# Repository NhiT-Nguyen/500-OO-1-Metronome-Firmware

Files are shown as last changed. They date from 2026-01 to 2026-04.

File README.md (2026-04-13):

# Metronome Glasses Firmware

The firmware of Metrnome Glasses was developed with Arduino and the Espressif ESP32 Library.
Other libraries were used to implement video on the glasses, and an I2S Protocol was used for the associated audio.

# Mechanical Enclosure

Included in this repository are the .stl files needed to 3D print the mechanical frame of the glasses.
The design of these parts were largely adapted from the Mentra Open Source Smart Glasses,
with adaptations made by the Tempo Titans team to suit our use case.

# Altium Design Files - PCB
This repository contains the PCB design files for the Tempo Titans custom board, designed in Altium Designer and fabricated by JLCPCB.

# Sister Repository

This repository is the sister repository of the Flutter app used to configure the glasses' metronome settings.

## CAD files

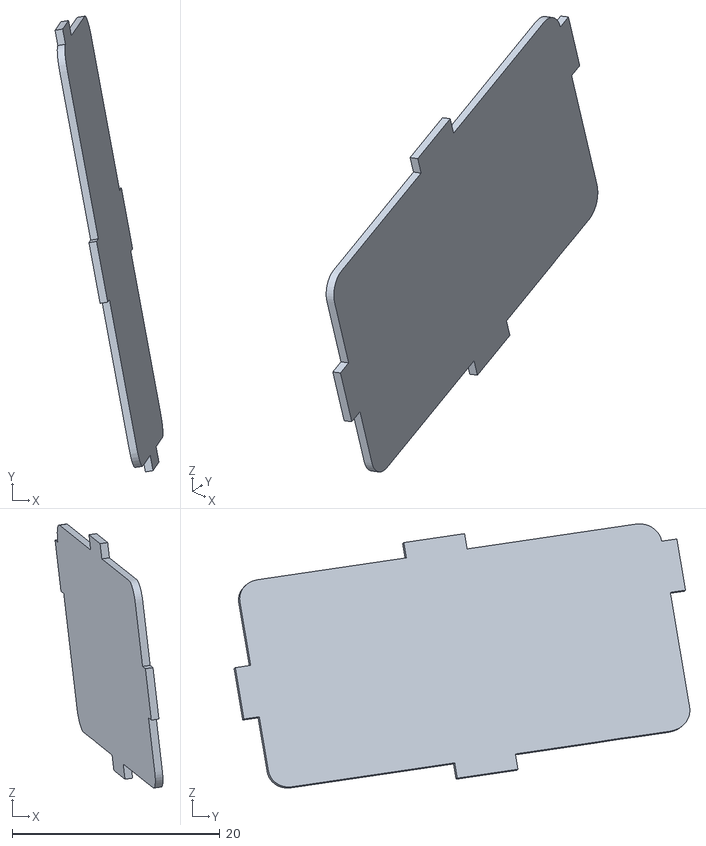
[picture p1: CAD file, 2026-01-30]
Mechanical Enclosure/MAIN_FRAME_Fusion_BATTERY_COVER_RIGHT.stl
10.4 x 43.8 x 25.4

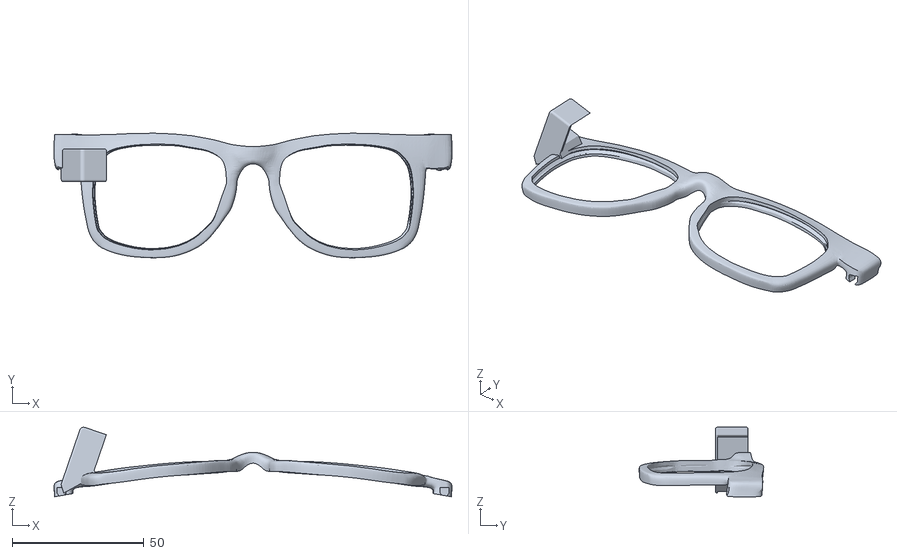
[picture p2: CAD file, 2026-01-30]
Mechanical Enclosure/MAIN_FRAME_Fusion_FRONT.stl
151.0 x 47.3 x 26.4

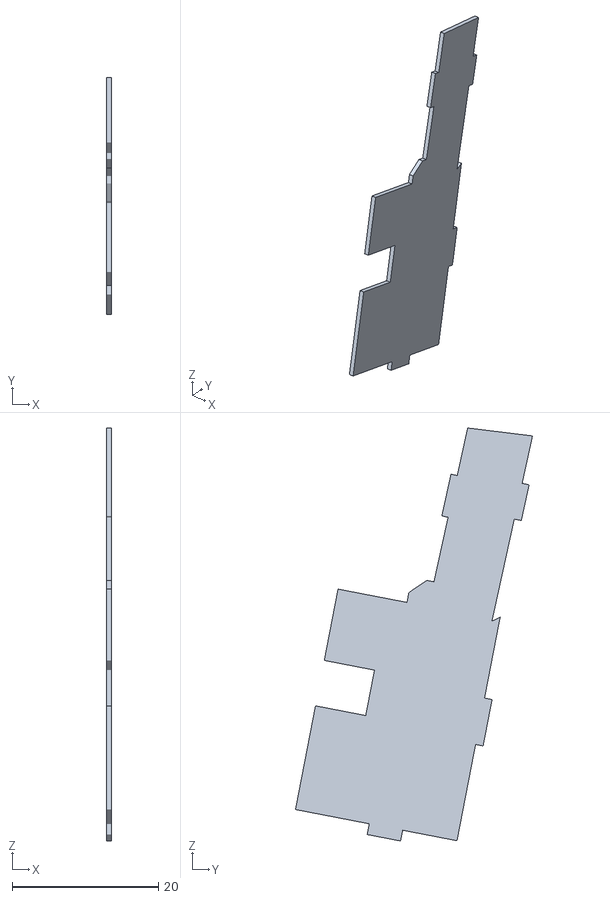
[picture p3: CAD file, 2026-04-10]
Mechanical Enclosure/RIGHT_ARM_COVER.stl
0.75 x 32.4 x 56.5

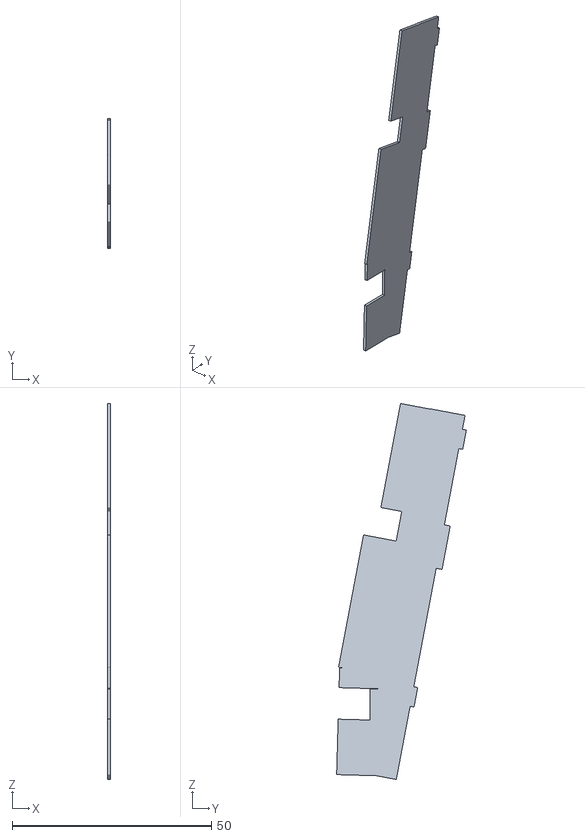
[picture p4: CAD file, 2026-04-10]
Mechanical Enclosure/LEFT_ARM_COVER.stl
0.75 x 32.6 x 94.5

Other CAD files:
Mechanical Enclosure/MAIN_FRAME_Fusion_BATTERY_COVER_LEFT.stl

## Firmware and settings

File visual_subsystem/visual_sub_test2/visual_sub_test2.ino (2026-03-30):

/*
 * Tempo Titans - Subdivisions + Tone Synthesis Edition
 *
 * Ported from metronome_logic.dart
 *
 * Key additions vs. the SPIFFS WAV edition
 * ─────────────────────────────────────────
 * • Per-beat sound MODE  (0-4) — replaces the hard-coded beat→WAV mapping
 * • Per-beat SUBDIVISIONS (2-4 sub-ticks per beat, each with its own mode)
 * • Synthesised tones replace WAV files — no SPIFFS upload needed
 * • Beat boxes AND subdivision dots are coloured by their assigned mode
 * • Drift-corrected tick scheduling (mirrors the Dart Stopwatch approach)
 *
 * Mode → Sound / Colour table
 * ───────────────────────────
 *  Mode 0  bell    1400 Hz, 80 ms fade   Yellow  (0xFC)
 *  Mode 1  click   1000 Hz, 30 ms sharp  Green   (0x1C)
 *  Mode 2  tick     700 Hz, 20 ms short  Cyan    (0x1F)
 *  Mode 3  drum     200 Hz, 60 ms thud   Red     (0xE0)
 *  Mode 4  silent  (no sound)            Grey    (0x49)
 *
 * Display Wiring:
 *   AV+ (Yellow) -> GPIO 25
 *   GND          -> GND
 *   5V           -> 5V
 *
 * MAX98357A Wiring:
 *   Vin  -> 5V
 *   GND  -> GND
 *   BCLK -> GPIO 14
 *   LRC  -> GPIO 13
 *   DIN  -> GPIO 27
 *
 * Fixes applied vs. visual_sub_test2.ino
 * ───────────────────────────────────────
 * FIX 1 — Removed videoOut.copyAfterSwap = true
 *          That flag caused intermittent screen blanking when combined with a
 *          full redraw every frame.  Since we call fillScreen + all draw
 *          functions every loop iteration anyway, the copy is unnecessary.
 *
 * FIX 2 — Clamp tone duration to sub-interval in playTone()
 *          The blocking i2s_write loop was able to run longer than one
 *          sub-interval at high BPM, causing missed ticks.  The duration is
 *          now capped to (subInterval - 5 ms) so timing is always recovered.
 *
 * FIX 3 — getNextIntervalUs() called AFTER advanceSubdivision()
 *          Previously the interval was sampled before the beat state advanced,
 *          so a beat boundary tick used the old beat's subdivision count.
 *          Moving the sample after the advance ensures the correct interval is
 *          stored into nextTickUs.
 */

#include "ESP_8_BIT_GFX.h"
#include "driver/i2s.h"
#include <math.h>

// ── Video ────────────────────────────────────────────────────────────────────
ESP_8_BIT_GFX videoOut(true, 8);   // NTSC, 8-bit colour
// NOTE: copyAfterSwap intentionally NOT set — it caused random screen blanking.

// ── I2S pins ─────────────────────────────────────────────────────────────────
#define I2S_BCLK  14
#define I2S_LRC   13
#define I2S_DOUT  27
#define SAMPLE_RATE 16000

// ── Beat / subdivision limits ─────────────────────────────────────────────────
#define MAX_BEATS     4
#define MAX_SUBS      4   // max subdivisions per beat (2-4 allowed)
#define NUM_MODES     5   // modes 0-4

// ── Mode colour table (8-bit NTSC palette) ────────────────────────────────────
//  Index matches the mode integer sent from the Flutter app / set locally.
const uint8_t MODE_COLORS[NUM_MODES] = {
  0xFC,   // 0 bell    — Yellow
  0x1C,   // 1 click   — Green
  0x1F,   // 2 tick    — Cyan
  0xE0,   // 3 drum    — Red
  0x49,   // 4 silent  — Dark grey
};

// ── Tone parameters per mode ──────────────────────────────────────────────────
struct ToneParams { int freqHz; int durationMs; };
const ToneParams TONE_TABLE[NUM_MODES] = {
  {1400, 80 },   // 0 bell
  {1000, 30 },   // 1 click
  { 700, 20 },   // 2 tick
  { 200, 60 },   // 3 drum
  {   0,  0 },   // 4 silent
};

// ── Metronome state ───────────────────────────────────────────────────────────
int  bpm              = 100;
int  meterBeats       = 4;     // beats per measure (2, 3, or 4)

int  activeBeat       = 0;     // 0-indexed current beat
int  activeSubdivision= 0;     // 0-indexed subdivision within activeBeat

// beatModes[b]         : sound mode for beat b  (0-4)
// subdivisionModes[b][s]: sound mode for subdivision s of beat b
// showSubdivisions[b]  : whether beat b plays sub-ticks
// beatSubdivisions[b]  : how many sub-ticks beat b has (2-4)
int  beatModes[MAX_BEATS]                   = {0, 1, 1, 1};
int  subdivisionModes[MAX_BEATS][MAX_SUBS]  = {
       {2, 2, 2, 2},
       {2, 2, 2, 2},
       {2, 2, 2, 2},
       {2, 2, 2, 2},
     };
bool showSubdivisions[MAX_BEATS]            = {true, false, true, false};
int  beatSubdivisions[MAX_BEATS]            = {4, 4, 4, 4};

// ── Drift-corrected timing (mirrors Dart Stopwatch approach) ──────────────────
// Instead of scheduling each tick relative to the previous callback time
// (which drifts), we track an absolute target in microseconds since boot.
// Each tick advances the target by the fixed interval, so a late callback
// simply schedules the next one sooner rather than sliding the whole timeline.
unsigned long nextTickUs  = 0;   // absolute target (micros())
bool          firstBeat   = true;

// ── Display layout constants ──────────────────────────────────────────────────
#define SCREEN_W   256
#define SCREEN_H   240

#define BOX_W       50
#define BOX_H       50
#define BOX_GAP     10
#define BOX_START_X 13
#define BOX_Y       20

#define SUB_DOT_R   5          // subdivision dot radius
#define SUB_ROW_Y   (BOX_Y + BOX_H + 14)  // vertical centre of sub dots

// ── Colours ───────────────────────────────────────────────────────────────────
#define COL_BG      0x02   // dark blue background
#define COL_BOX     0x03   // inactive beat box
#define COL_TEXT    0xFF   // white text
#define COL_ACTIVE_BORDER 0xFF  // white border on active box

// ─────────────────────────────────────────────────────────────────────────────
//  Interval helpers  (mirrors Dart beatInterval / subdivisionInterval)
//  Declared before playTone so the duration clamp can call subIntervalUs().
// ─────────────────────────────────────────────────────────────────────────────
unsigned long beatIntervalUs() {
  return (unsigned long)(60000000UL / bpm);
}

unsigned long subIntervalUs(int beatIndex) {
  int subs = beatSubdivisions[beatIndex];
  return beatIntervalUs() / subs;
}

// Returns the interval that should follow the CURRENT tick position
unsigned long getNextIntervalUs() {
  if (showSubdivisions[activeBeat]) {
    return subIntervalUs(activeBeat);
  }
  return beatIntervalUs();
}

// ─────────────────────────────────────────────────────────────────────────────
//  Tone synthesis
//  Generates a sine wave with a linear fade-out envelope and streams it to I2S.
//
//  FIX 2: Duration is clamped to (current sub-interval - 5 ms) so the blocking
//  write loop can never overrun the next tick deadline.
// ─────────────────────────────────────────────────────────────────────────────
void playTone(int freqHz, int durationMs) {
  if (freqHz == 0 || durationMs == 0) return;   // mode 4 — silent

  // Clamp duration so we never block longer than one sub-interval.
  // Leave a 5 ms margin for the rest of loop() work.
  unsigned long maxMs = getNextIntervalUs() / 1000UL;
  if (maxMs > 5 && durationMs > (int)(maxMs - 5)) {
    durationMs = (int)(maxMs - 5);
  }
  if (durationMs <= 0) return;

  int totalSamples = (long)SAMPLE_RATE * durationMs / 1000;
  size_t bw;

  for (int i = 0; i < totalSamples; i++) {
    float env  = 1.0f - ((float)i / totalSamples);   // linear decay
    float wave = sinf(2.0f * PI * freqHz * i / (float)SAMPLE_RATE);
    int16_t s  = (int16_t)(wave * env * 0.75f * 32000);
    int16_t lr[2] = {s, s};
    i2s_write(I2S_NUM_1, lr, sizeof(lr), &bw, portMAX_DELAY);
  }
}

// Play the tone associated with a mode integer
void playMode(int mode) {
  if (mode < 0 || mode >= NUM_MODES) mode = 0;
  playTone(TONE_TABLE[mode].freqHz, TONE_TABLE[mode].durationMs);
}

// ─────────────────────────────────────────────────────────────────────────────
//  I2S setup  (I2S_NUM_1 — video driver owns I2S_NUM_0)
// ─────────────────────────────────────────────────────────────────────────────
void setupI2S() {
  i2s_config_t cfg = {
    .mode                = (i2s_mode_t)(I2S_MODE_MASTER | I2S_MODE_TX),
    .sample_rate         = SAMPLE_RATE,
    .bits_per_sample     = I2S_BITS_PER_SAMPLE_16BIT,
    .channel_format      = I2S_CHANNEL_FMT_RIGHT_LEFT,
    .communication_format= I2S_COMM_FORMAT_STAND_I2S,
    .intr_alloc_flags    = ESP_INTR_FLAG_LEVEL1,
    .dma_buf_count       = 8,
    .dma_buf_len         = 64,
    .use_apll            = false,
    .tx_desc_auto_clear  = true
  };
  i2s_pin_config_t pins = {
    .bck_io_num   = I2S_BCLK,
    .ws_io_num    = I2S_LRC,
    .data_out_num = I2S_DOUT,
    .data_in_num  = I2S_PIN_NO_CHANGE
  };
  i2s_driver_install(I2S_NUM_1, &cfg, 0, NULL);
  i2s_set_pin(I2S_NUM_1, &pins);
}

// ─────────────────────────────────────────────────────────────────────────────
//  Advance logic  (mirrors advanceBeat / advanceSubdivision in Dart)
// ─────────────────────────────────────────────────────────────────────────────
void advanceBeat() {
  activeBeat = (activeBeat + 1) % meterBeats;
  activeSubdivision = 0;

  // Play beat sound (first subdivision sound if subs enabled)
  if (showSubdivisions[activeBeat])
    playMode(subdivisionModes[activeBeat][0]);
  else
    playMode(beatModes[activeBeat]);
}

void advanceSubdivision() {
  bool hasSubs = showSubdivisions[activeBeat];
  if (hasSubs) {
    int subCount = beatSubdivisions[activeBeat];
    if (activeSubdivision < subCount - 1) {
      activeSubdivision++;
      playMode(subdivisionModes[activeBeat][activeSubdivision]);
    } else {
      advanceBeat();
    }
  } else {
    advanceBeat();
  }
}

// ─────────────────────────────────────────────────────────────────────────────
//  Display helpers
// ─────────────────────────────────────────────────────────────────────────────

// Returns the x-left of beat box [i]
int boxX(int i) {
  return BOX_START_X + i * (BOX_W + BOX_GAP);
}

// Draws beat boxes with mode-colour fill and white border when active
void drawBeatBoxes() {
  for (int i = 0; i < meterBeats; i++) {
    int x    = boxX(i);
    bool act = (i == activeBeat && activeSubdivision == 0);

    uint8_t fillCol = MODE_COLORS[beatModes[i]];

    if (act) {
      // Brighter: draw a white border then fill inside
      videoOut.fillRect(x, BOX_Y, BOX_W, BOX_H, COL_ACTIVE_BORDER);
      videoOut.fillRect(x + 2, BOX_Y + 2, BOX_W - 4, BOX_H - 4, fillCol);
    } else {
      videoOut.fillRect(x, BOX_Y, BOX_W, BOX_H, fillCol);
    }

    // Beat number centred in box
    videoOut.setTextSize(2);
    videoOut.setTextColor(act ? 0x00 : COL_TEXT);
    videoOut.setCursor(x + 18, BOX_Y + 17);
    videoOut.print(i + 1);
  }
}

// Draws subdivision dots beneath each beat box
// Active subdivision glows white-bordered; others coloured by their mode
void drawSubdivisionDots() {
  for (int b = 0; b < meterBeats; b++) {
    if (!showSubdivisions[b]) continue;

    int subCount = beatSubdivisions[b];
    int bx       = boxX(b);
    // Evenly space dots within the beat box column
    int slotW    = BOX_W / subCount;

    for (int s = 0; s < subCount; s++) {
      int cx    = bx + slotW * s + slotW / 2;
      int cy    = SUB_ROW_Y;
      bool act  = (b == activeBeat && s == activeSubdivision);

      uint8_t dotCol = MODE_COLORS[subdivisionModes[b][s]];

      if (act) {
        videoOut.fillCircle(cx, cy, SUB_DOT_R + 2, COL_ACTIVE_BORDER);
        videoOut.fillCircle(cx, cy, SUB_DOT_R,     dotCol);
      } else {
        videoOut.fillCircle(cx, cy, SUB_DOT_R, dotCol);
      }
    }
  }
}

void drawBpmDisplay() {
  videoOut.setTextColor(COL_TEXT);
  videoOut.setTextSize(2);
  videoOut.setCursor(50, 110);
  videoOut.print("Current BPM:");

  videoOut.setTextSize(4);
  videoOut.setCursor(bpm < 100 ? 95 : 75, 145);
  videoOut.print(bpm);
}

// ─────────────────────────────────────────────────────────────────────────────
void setup() {
  Serial.begin(115200);
  Serial.println("Tempo Titans - Subdivisions + Tone Edition");

  videoOut.begin();
  // FIX 1: copyAfterSwap removed — caused random screen blanking.
  // Full redraw every frame makes it unnecessary.

  setupI2S();

  // Startup bell
  playMode(0);

  // Prime the absolute tick clock: first beat fires immediately
  nextTickUs = micros();
  firstBeat  = true;

  Serial.println("Ready!");
}

// ─────────────────────────────────────────────────────────────────────────────
void loop() {
  // ── Tick / beat advancement ───────────────────────────────────────────────
  unsigned long now = micros();

  if (firstBeat) {
    // Play beat 0 immediately on start
    activeBeat        = 0;
    activeSubdivision = 0;
    playMode(showSubdivisions[0] ? subdivisionModes[0][0] : beatModes[0]);
    nextTickUs = now + getNextIntervalUs();
    firstBeat  = false;
  } else if (now >= nextTickUs) {
    // FIX 3: advanceSubdivision() is called FIRST so that activeBeat /
    // activeSubdivision reflect the new position before we sample the
    // interval.  Previously the interval was read before the advance, so a
    // beat-boundary tick used the old beat's subdivision count.
    advanceSubdivision();

    // Drift correction: advance target by the interval, not from 'now',
    // so accumulated jitter doesn't shift the whole timeline.
    unsigned long interval = getNextIntervalUs();   // sampled after advance
    nextTickUs += interval;

    // If we're running very late (e.g. audio took too long), re-anchor
    // to avoid a burst of catch-up ticks.
    if (micros() > nextTickUs + interval) {
      nextTickUs = micros() + interval;
    }

    Serial.printf("Beat %d  Sub %d\n", activeBeat, activeSubdivision);
  }

  // ── Display ───────────────────────────────────────────────────────────────
  videoOut.waitForFrame();
  videoOut.fillScreen(COL_BG);

  drawBeatBoxes();
  drawSubdivisionDots();
  drawBpmDisplay();
}

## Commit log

2026-01-30 Add files via upload
    stl files for glasses enclosure
    [MAIN_FRAME_Fusion_BATTERY_COVER_LEFT.stl, MAIN_FRAME_Fusion_BATTERY_COVER_RIGHT.stl, MAIN_FRAME_Fusion_FRONT.stl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]
2026-04-10 Removed Brilliant labs firmware unrelated to our project
    Updated .stl files are in the OneDrive, to be added in next commit
    [MAIN_FRAME_Fusion_BATTERY_COVER_LEFT.stl, MAIN_FRAME_Fusion_BATTERY_COVER_RIGHT.stl, MAIN_FRAME_Fusion_FRONT.stl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]
2026-04-10 .stl files from Shared OneDrive
    [LEFT_ARM_COVER.stl, MAIN_FRAME_Fusion_BATTERY_COVER_LEFT.stl, MAIN_FRAME_Fusion_BATTERY_COVER_RIGHT.stl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]
